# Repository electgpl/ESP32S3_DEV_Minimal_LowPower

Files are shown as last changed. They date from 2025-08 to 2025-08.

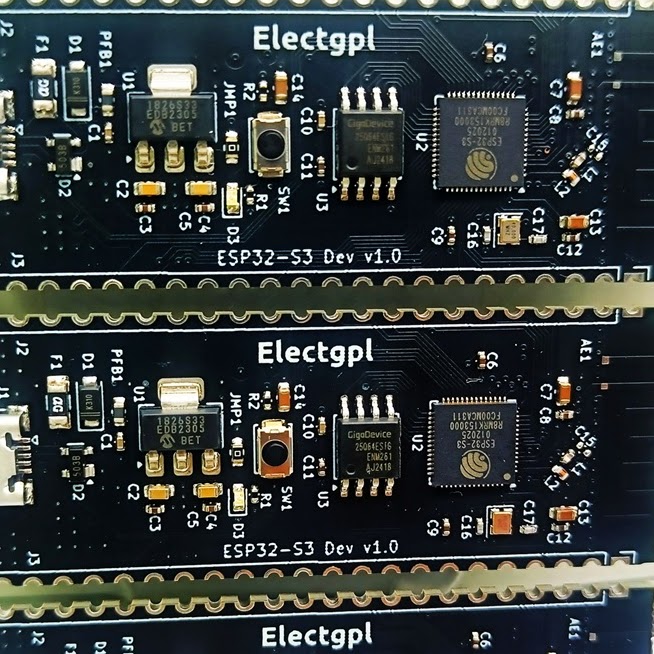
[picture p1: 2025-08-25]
Resources/wKgZO2gYVwOAP5xqADixpduBXg466aaa.jpg

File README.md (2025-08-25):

# ESP32S3_DEV_Minimal_LowPower

This project implements a **minimal low-power development board** based on the **ESP32-S3**.  
The design focuses on reducing component count, board complexity, and idle power consumption, while still exposing the full capabilities of the ESP32-S3 for advanced development.  

Unlike traditional development boards, this design does **not include a USB-to-UART bridge**. Instead, it leverages the **native USB interface** of the ESP32-S3 for programming and communication, resulting in a simpler and more efficient design.  

---

## 🔑 Features

- **ESP32-S3 MCU** with external **QSPI Flash memory**.  
- **Native USB 2.0 interface** used for flashing and serial communication.  
- **MCP1826S LDO regulator**:  
  - Low quiescent current (IQ) for low-power operation.  
  - Stable supply for ESP32-S3 core.  
- **4-layer PCB**:  
  - Designed and manufactured at **NextPCB (PCBA service)**.  
  - Optimized for **low EMI/EMC compliance**.  
- **Castellated edges** for easy integration into other projects.  
- **Full pinout exposure**:  
  - All ESP32-S3 GPIOs available, including those not accessible on standard WROOM modules.  
  - Enables advanced use cases and maximum flexibility.  
- **On-board PCB antenna (MIFA type)**:  
  - Designed with **uSimmics EM simulation**.  
  - Verified radiation characteristics, dispersion parameters, and stack-up effects.  

---

## 📂 Repository structure

- **/schematic/** → Circuit schematic files.  
- **/pcb/** → PCB layout and Gerber files.  
- **/doc/** → Antenna simulation results and design notes.  
- **/firmware/** → Demo applications and example projects.  
- **/img/** → PCB renders and prototype photos.  

---

## 🧪 Demo Application

Included with this project is a **human presence detection demo** based on Wi-Fi spectral footprint analysis:  

- Scans available Wi-Fi networks, collecting **SSID** and **RSSI** values.  
- Applies a **probability-based algorithm** using **normal distribution** to estimate environmental changes.  
- Detects human presence based on variations in the Wi-Fi spectrum.  
- Displays results on a **color IPS display**.  

This demonstrates the potential of the ESP32-S3 in **low-cost sensing and AIoT applications** without requiring dedicated motion sensors.  

---

## 🔧 Typical applications

- Low-power IoT node development.  
- Integration into custom PCBs via castellated module design.  
- Edge-AI and machine learning applications.  
- Antenna research and RF prototyping.  

---

## 📑 References

- [ESP32-S3 Technical Reference Manual (Espressif)](https://www.espressif.com/en/support/download/technical-documents)  
- [MCP1826S LDO Datasheet (Microchip)](https://ww1.microchip.com/downloads/en/DeviceDoc/22057B.pdf)  
- [uSimmics EM Simulation Software](https://www.usimmics.com/)  

---

## 📸 Project preview

*(Insert here PCB renders, antenna simulation plots, and prototype photos)*  

---

## ⚖️ License

This project is released under the **MIT License**.  
You are free to use, modify, and distribute it, provided that proper credit is given.  

---

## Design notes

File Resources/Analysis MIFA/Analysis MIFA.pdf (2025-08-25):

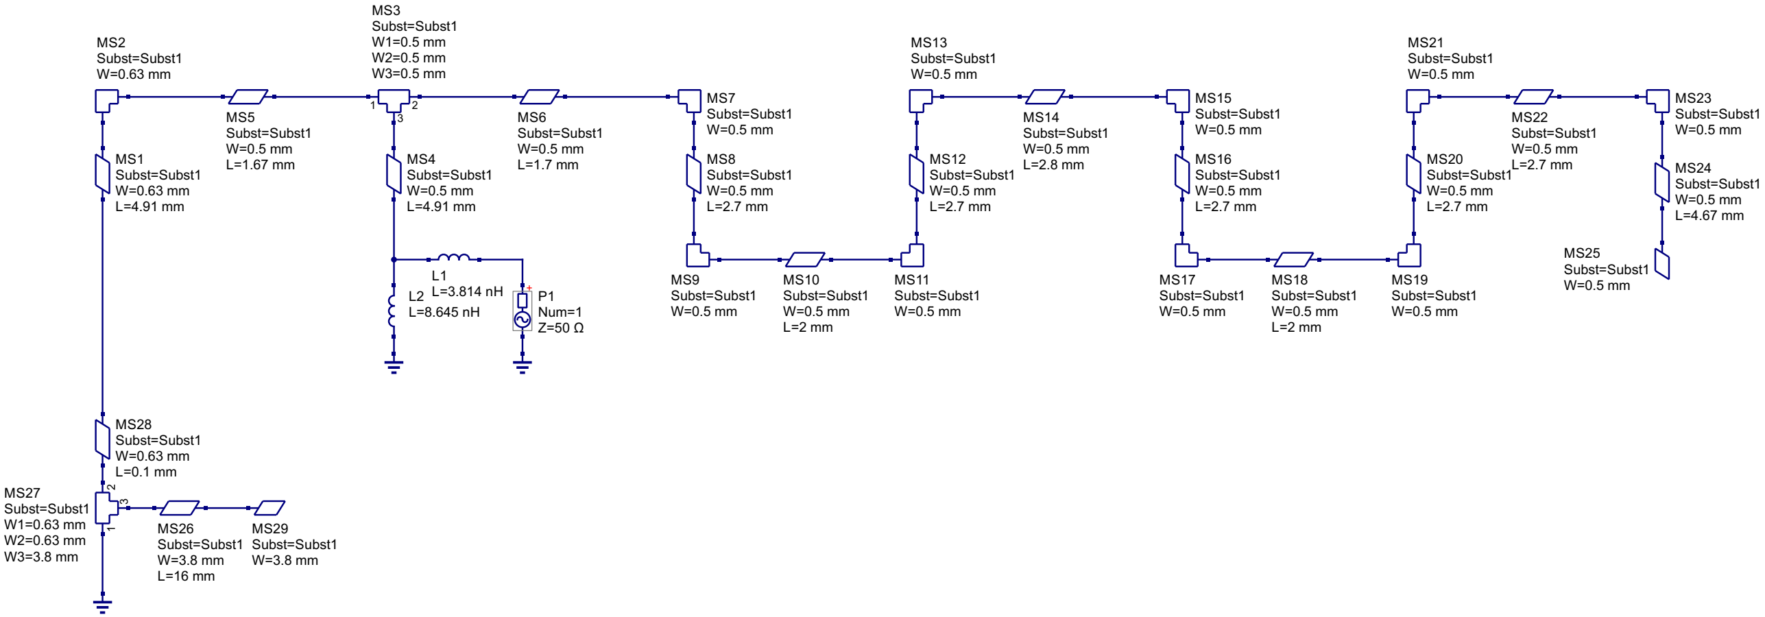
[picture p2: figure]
MS1 Subst=Subst1 W=0.63 mm L=4.91 mm; MS2 Subst=Subst1 W=0.63 mm; MS5 Subst=Subst1 W=0.5 mm L=1.67 mm; MS6 Subst=Subst1 W=0.5 mm L=1.7 mm; MS3 Subst=Subst1 W1=0.5 mm W2=0.5 mm W3=0.5 mm; MS4 Subst=Subst1 W=0.5 mm L=4.91 mm; MS7 Subst=Subst1 W=0.5 mm; MS8 Subst=Subst1 W=0.5 mm L=2.7 mm; MS9 Subst=Subst1 W=0.5 mm; MS10 Subst=Subst1 W=0.5 mm L=2 mm; MS11 Subst=Subst1 W=0.5 mm; MS12 Subst=Subst1 W=0.5 mm L=2.7 mm; MS14 Subst=Subst1 W=0.5 mm L=2.8 mm; MS15 Subst=Subst1 W=0.5 mm; MS16 Subst=Subst1 W=0.5 mm L=2.7 mm; MS17 Subst=Subst1 W=0.5 mm; MS18 Subst=Subst1 W=0.5 mm L=2 mm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

Subst1
er=4.5
h=1.6 mm
t=35 µm
tand=2e-4
rho=1.72e-8
backside=Metal

### s-parameter simulation

SP1
Type=lin Start=2.3 GHz Stop=2.5 GHz Points=1000

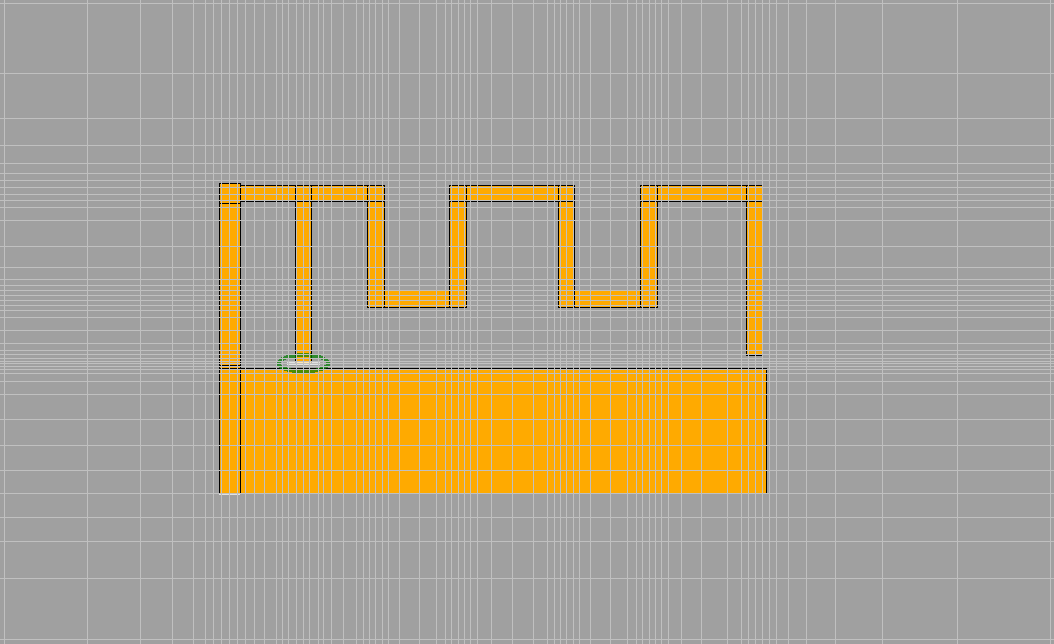
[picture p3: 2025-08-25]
Resources/Analysis MIFA/Captura de pantalla 2025-07-07 103250.png

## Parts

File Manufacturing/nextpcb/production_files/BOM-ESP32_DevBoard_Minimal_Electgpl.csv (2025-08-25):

MPN | Qty | Designator | value | manufacturer | Category | SKU | Customer Supply | Customer Remark
 | 1 | AE1 | Antenna_Shield
 | 6 | C7,C14,C5,C2,C13,PFB1 | 10u
 | 14 | C11,C12,C9,C4,C17,C6,C8,L1,C3,C1,C10,C15,L2,C16 | 100n
 | 1 | D1 | DS310W
 | 1 | D2 | SP0503BAHTG
 | 1 | D3 | LED
 | 1 | F1 | nSMD150
 | 1 | J1 | U254-051T-4BH83-F1S
 | 2 | J3,J2 | Conn_01x22_Pin
 | 1 | JMP1 | 0R
 | 2 | R1,R2 | 10k
 | 1 | SW1 | SW_Push
 | 1 | U1 | MCP1826S-3302E/DB
 | 1 | U2 | ESP32-S3
 | 1 | U3 | W25Q64JVSSIQ
 | 1 | Y1 | R940000096

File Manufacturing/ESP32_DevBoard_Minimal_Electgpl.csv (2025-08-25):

Designator* | Quantity* | Manufacturer Part Number* | Manufacturer | Package/Footprint | Description | Procurement Type | Customer Note
AE1 | 1 |  |  | ESP_Antenna:ESPRESSIF_ESP32_MIFA_2.4GHz_Right |  | DNP
C1,C10 | 2 | CL05X105KP5NNNC |  | Capacitor_SMD:C_0402_1005Metric |  |  | CA0157860
C2,C5 | 2 | GRM188R60J476ME15D |  | Capacitor_SMD:C_0603_1608Metric |  |  | CA0135493
C3,C4,C6,C8,C9,C11,C12 | 7 | CC0402KRX7R9BB104 |  | Capacitor_SMD:C_0402_1005Metric |  |  | RE0187778
C7,C13,C14 | 3 | GCM188D70J106ME36D |  | Capacitor_SMD:C_0603_1608Metric |  |  | CA0384128
C15 | 1 |  |  | Capacitor_SMD:C_0402_1005Metric |  | DNP
C16,C17 | 2 | GRM1555C1H100GA01D |  | Capacitor_SMD:C_0402_1005Metric |  |  | CA0137027
D1 | 1 | DS310W |  | Diode_SMD:D_SOD-123 |  |  | DS0182252
D2 | 1 | SP0503BAHTG |  | Package_TO_SOT_SMD:SOT-143 |  |  | CP0003989
D3 | 1 | TJ-S1608B06HQYJY-A3 |  | LED_SMD:LED_0603_1608Metric |  |  | PH0093820
F1 | 1 | nSMD075-16V |  | Fuse:Fuse_1206_3216Metric_Pad1.42x1.75mm_HandSolder |  |  | CP0107097
J1 | 1 | U254-051T-4BH83-F1S |  | Connector_USB:USB_Micro-B_XKB_U254-051T-4BH83-F1S |  |  | CO0893195
J2,J3 | 2 |  |  | Connector_PinHeader_2.54mm:PinHeader_1x22_P2.54mm_Vertical |  | DNP
JMP1 | 1 | AC0603JR-070RL |  | Resistor_SMD:R_0603_1608Metric |  |  | RE0030890
L1 | 1 | SCC1005C4N3SSP |  | Capacitor_SMD:C_0402_1005Metric |  |  | IN0076375
L2 | 1 | SCW1005C8N2JST |  | Capacitor_SMD:C_0402_1005Metric |  |  | IN0074484
PFB1 | 1 | BLM18SG331TN1D |  | Capacitor_SMD:C_0603_1608Metric |  |  | WF0011783
R1,R2 | 2 | RC0402JR-0710KL |  | Resistor_SMD:R_0402_1005Metric |  |  | RE0023874
SW1 | 1 | SKRKAEE020 |  | Button_Switch_SMD:SW_Push_SPST_NO_Alps_SKRK |  |  | SW0049182
U1 | 1 | MCP1826S-3302E/DB |  | Package_TO_SOT_SMD:SOT-223 |  |  | IC0133633
U2 | 1 | ESP32-S3R8 |  | Package_DFN_QFN:QFN-56-1EP_7x7mm_P0.4mm_EP5.6x5.6mm |  |  | RF15788811
U3 | 1 | GD25Q64ESIG |  | Package_SO:SOP-8_5.28x5.23mm_P1.27mm |  |  | IC0447018
Y1 | 1 | TAXM40M4ZHBCDT2T |  | Crystal:Crystal_SMD_2016-4Pin_2.0x1.6mm |  |  | C7206306

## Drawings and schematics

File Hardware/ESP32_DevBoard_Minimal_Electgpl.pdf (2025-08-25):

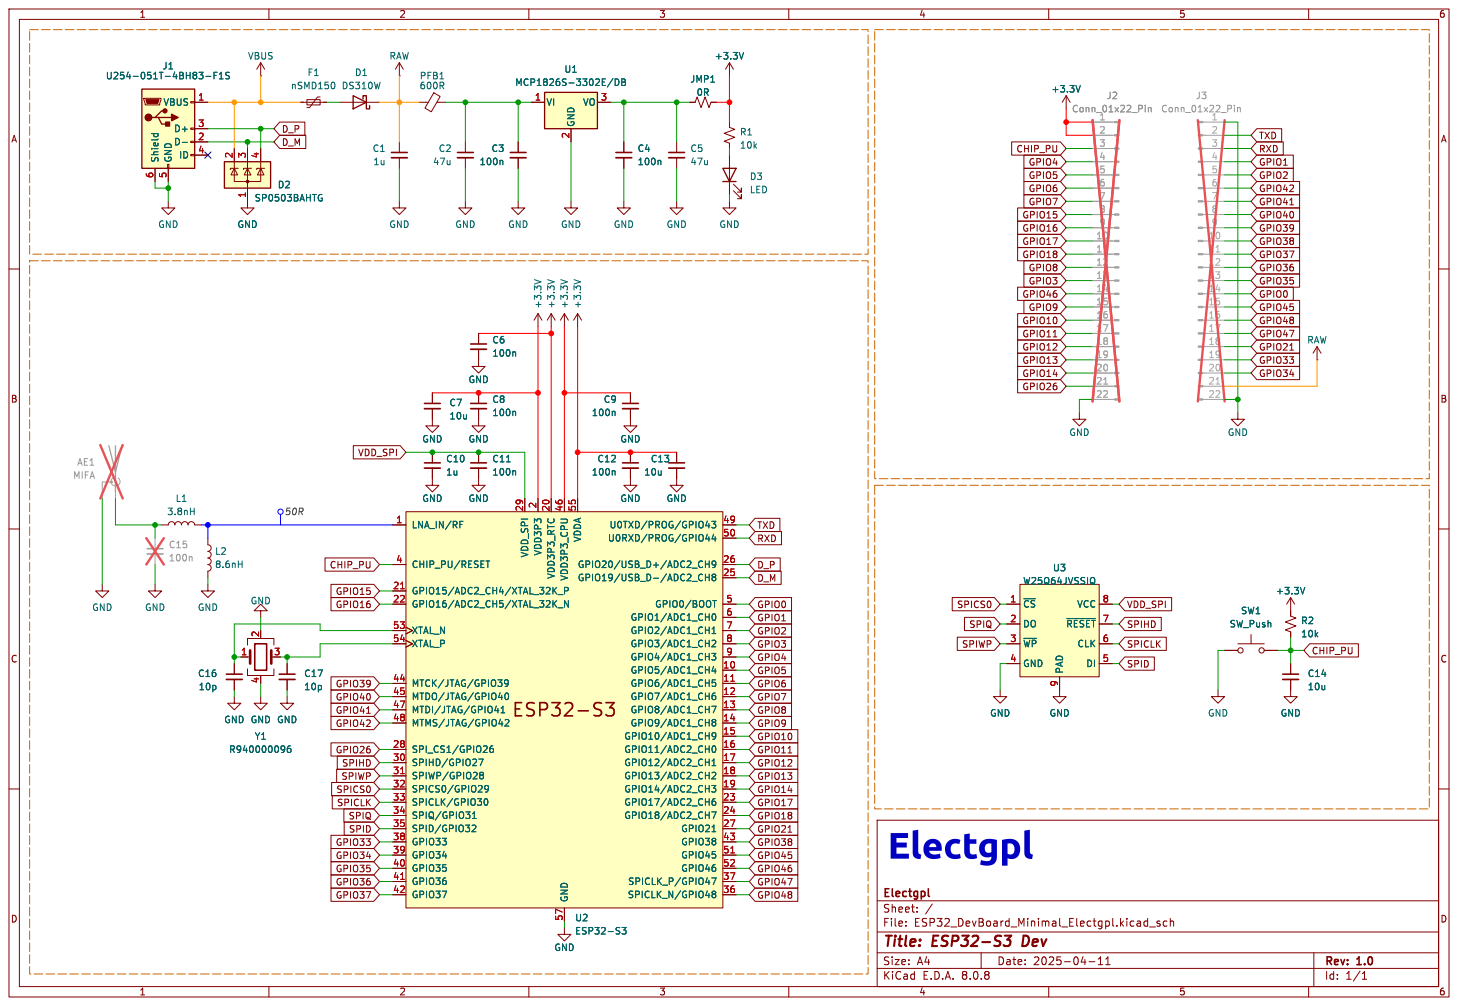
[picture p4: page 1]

2 VDD3P3_RTC 20 GPIO15/ADC2_CH4/XTAL_32K_P 21 GPIO16/ADC2_CH5/XTAL_32K_N 22 GPIO17/ADC2_CH6 23 GPIO18/ADC2_CH7 24 GPIO19/USB_D-/ADC2_CH8 25 GPIO20/USB_D+/ADC2_CH9 26 GPIO21 27 SPI_CS1/GPIO26 28 VDD_SPI 29 SPIHD/GPIO27 30 SPIWP/GPIO28 31 SPICS0/GPIO29 32 SPICLK/GPIO30 33 SPIQ/GPIO31 34 SPID/GPIO32 35 GPIO33 38 GPIO34 39 CHIP_PU/RESET 4 GPIO35 40 GPIO36 41 GPIO37 42 GPIO38 43 MTCK/JTAG/GPIO39 44 MTDO/JTAG/GPIO40 45 VDD3P3_CPU 46 MTDI/JTAG/GPIO41 47 MTMS/JTAG/GPIO42 48 U0TXD/PROG/GPIO43 49 GPIO0/BOOT 5 U0RXD/PROG/GPIO44 50 GPIO45 51 GPIO46 52 XTAL_N 53 XTAL_P 54 VDDA 55 GND 57 GPIO1/ADC1_CH0 6 GPIO2/ADC1_CH1 7 GPIO3/ADC1_CH2 8 GPIO4/ADC1_CH3 9 U2ESP32-S3

2 VDD3P3_RTC 20 GPIO15/ADC2_CH4/XTAL_32K_P 21 GPIO16/ADC2_CH5/XTAL_32K_N 22 GPIO17/ADC2_CH6 23 GPIO18/ADC2_CH7 24 GPIO19/USB_D-/ADC2_CH8 25 GPIO20/USB_D+/ADC2_CH9 26 GPIO21 27 SPI_CS1/GPIO26 28 VDD_SPI 29 SPIHD/GPIO27 30 SPIWP/GPIO28 31 SPICS0/GPIO29 32 SPICLK/GPIO30 33 SPIQ/GPIO31 34 SPID/GPIO32 35 GPIO33 38 GPIO34 39 CHIP_PU/RESET 4 GPIO35 40 GPIO36 41 GPIO37 42 GPIO38 43 MTCK/JTAG/GPIO39 44 MTDO/JTAG/GPIO40 45 VDD3P3_CPU 46 MTDI/JTAG/GPIO41 47 MTMS/JTAG/GPIO42 48 U0TXD/PROG/GPIO43 49 GPIO0/BOOT 5 U0RXD/PROG/GPIO44 50 GPIO45 51 GPIO46 52 XTAL_N 53 XTAL_P 54 VDDA 55 GND 57 GPIO1/ADC1_CH0 6 GPIO2/ADC1_CH1 7 GPIO3/ADC1_CH2 8 GPIO4/ADC1_CH3 9 GND

File: ESP32_DevBoard_Minimal_Electgpl.kicad_sch Sheet: / Electgpl GND

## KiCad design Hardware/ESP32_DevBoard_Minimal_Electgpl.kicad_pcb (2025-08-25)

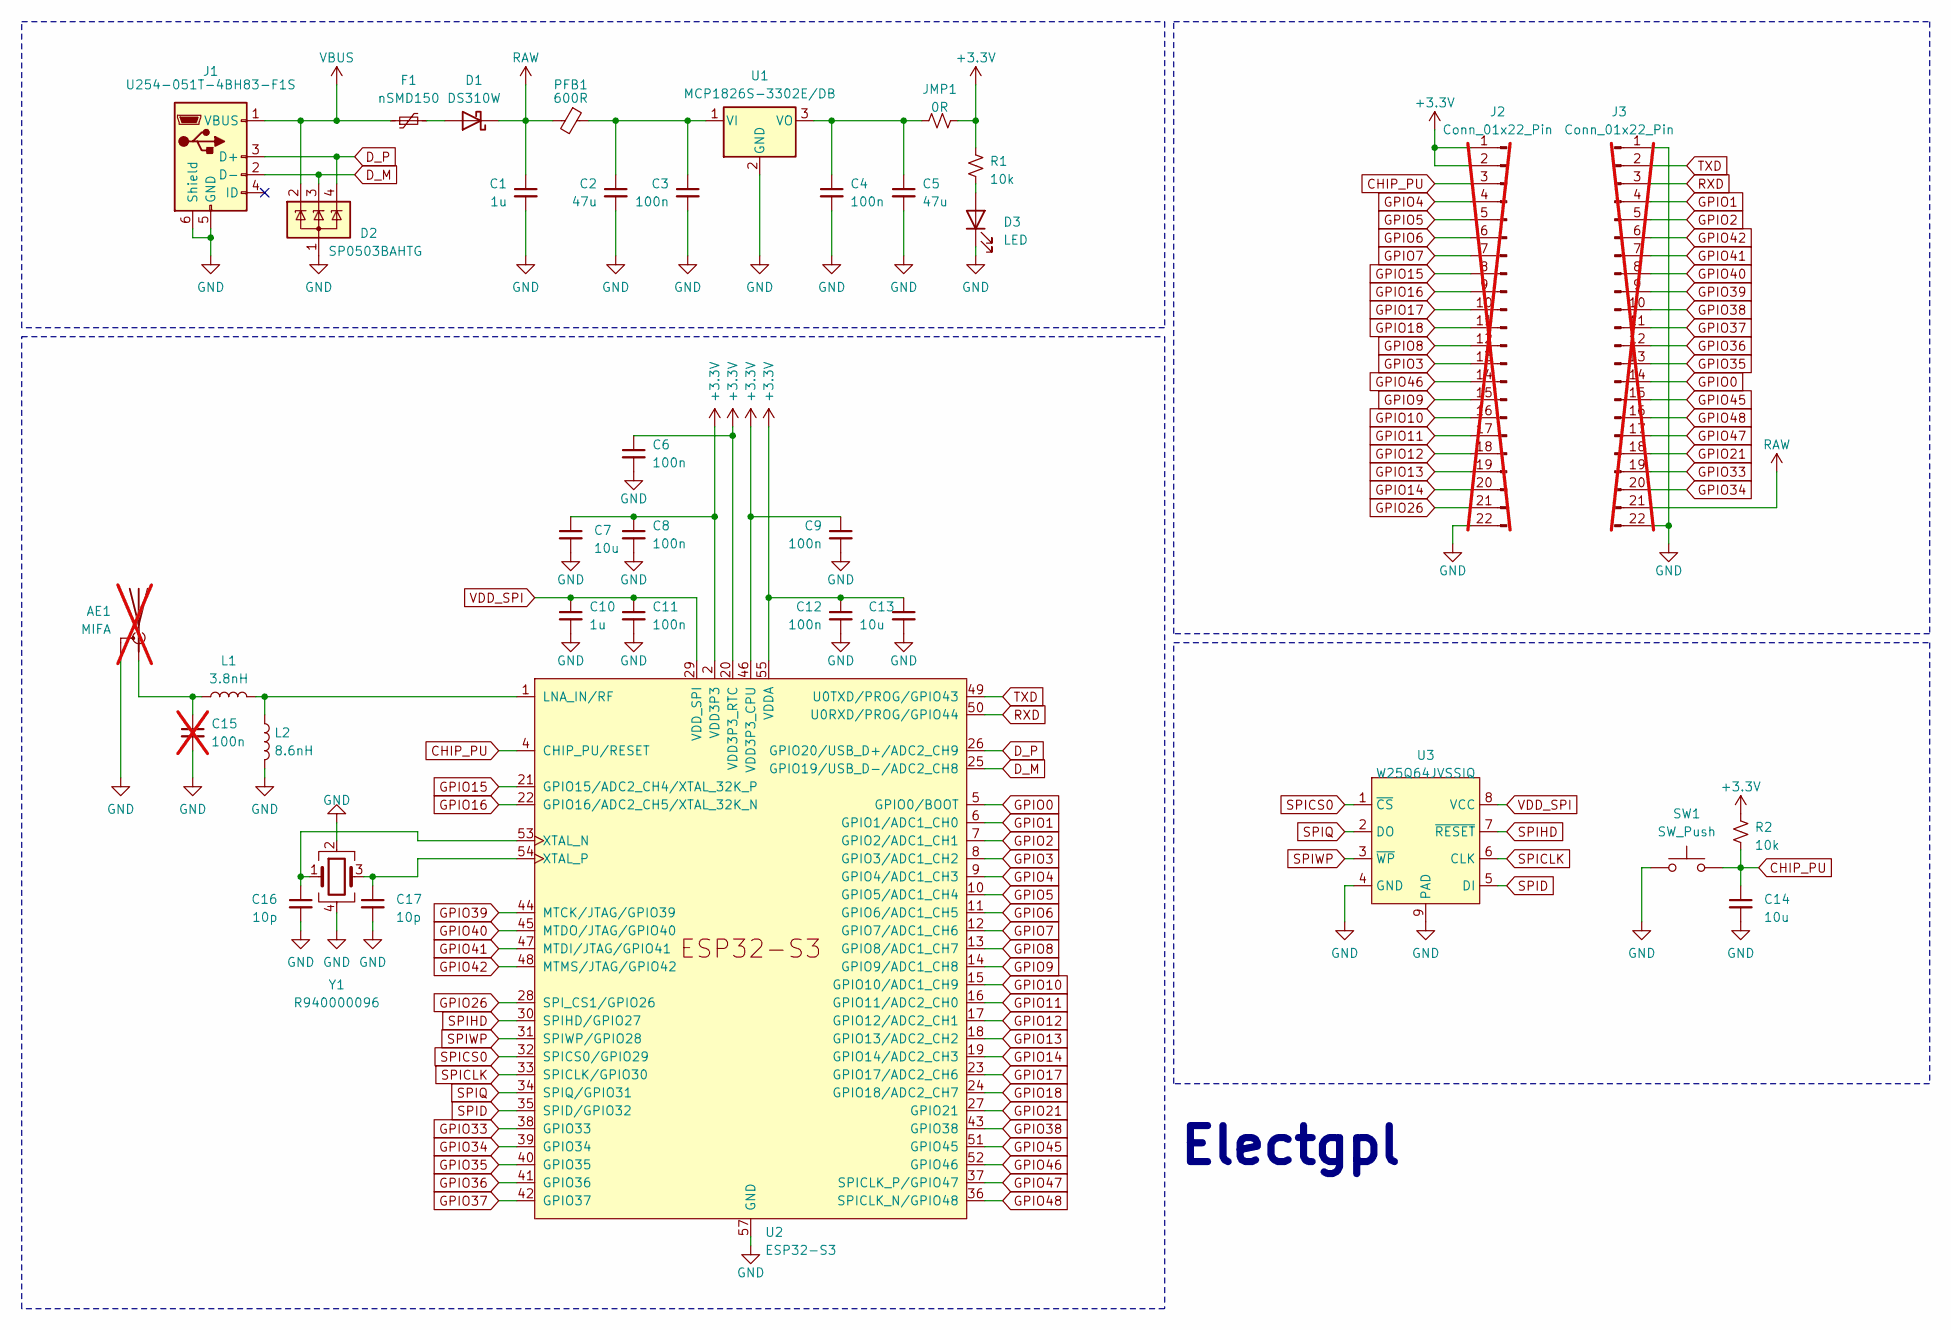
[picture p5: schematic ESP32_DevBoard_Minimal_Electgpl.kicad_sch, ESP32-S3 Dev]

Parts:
AE1: MIFA; ESPRESSIF_ESP32_MIFA_2.4GHz_Right; not fitted
C1, C10: 1u; C_0402_1005Metric; MFR P/N CL05X105KP5NNNC; LCSC CA0157860
C2, C5: 47u; C_0603_1608Metric; MFR P/N GRM188R60J476ME15D; LCSC CA0135493
C3, C4, C6, C8, C9, C11, C12: 100n; C_0402_1005Metric; MFR P/N CC0402KRX7R9BB104; LCSC RE0187778
C7, C13, C14: 10u; C_0603_1608Metric; MFR P/N GCM188D70J106ME36D; LCSC CA0384128
C15: 100n; C_0402_1005Metric; not fitted
C16, C17: 10p; C_0402_1005Metric; MFR P/N GRM1555C1H100GA01D; LCSC CA0137027
D1: DS310W; D_SOD-123; MFR P/N DS310W; LCSC DS0182252
D2: SP0503BAHTG; SOT-143; MFR P/N SP0503BAHTG; LCSC CP0003989
D3: LED; LED_0603_1608Metric; MFR P/N TJ-S1608B06HQYJY-A3; LCSC PH0093820
F1: nSMD150; Fuse_1206_3216Metric_Pad1.42x1.75mm_HandSolder; MFR P/N nSMD075-16V; LCSC CP0107097
J1: U254-051T-4BH83-F1S; USB_Micro-B_XKB_U254-051T-4BH83-F1S; MFR P/N U254-051T-4BH83-F1S; LCSC CO0893195
J2, J3: Conn_01x22_Pin; PinHeader_1x22_P2.54mm_Vertical; not fitted
JMP1: 0R; R_0603_1608Metric; MFR P/N AC0603JR-070RL; LCSC RE0030890
L1: 3.8nH; C_0402_1005Metric; MFR P/N SCC1005C4N3SSP; LCSC IN0076375
L2: 8.6nH; C_0402_1005Metric; MFR P/N SCW1005C8N2JST; LCSC IN0074484
PFB1: 600R; C_0603_1608Metric; MFR P/N BLM18SG331TN1D; LCSC WF0011783
R1, R2: 10k; R_0402_1005Metric; MFR P/N RC0402JR-0710KL; LCSC RE0023874
SW1: SW_Push; SW_Push_SPST_NO_Alps_SKRK; MFR P/N SKRKAEE020; LCSC SW0049182
U1: MCP1826S-3302E/DB; SOT-223; MFR P/N MCP1826S-3302E/DB; LCSC IC0133633
U2: ESP32-S3; QFN-56-1EP_7x7mm_P0.4mm_EP5.6x5.6mm; MFR P/N ESP32-S3R8; LCSC RF15788811
U3: W25Q64JVSSIQ; SOP-8_5.28x5.23mm_P1.27mm; MFR P/N GD25Q64ESIG; LCSC IC0447018
Y1: R940000096; Crystal_SMD_2016-4Pin_2.0x1.6mm; MFR P/N TAXM40M4ZHBCDT2T; LCSC C7206306

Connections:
+3.3V: C6.1, C7.1, C8.1, C9.1, C12.1, C13.1, J2.1, J2.2, JMP1.2, R1.1, R2.1, U2.2 (VDD3P3), U2.3 (VDD3P3), U2.20 (VDD3P3_RTC), U2.46 (VDD3P3_CPU), U2.55 (VDDA), U2.56 (VDDA)
CHIP_PU: C14.1, J2.3, R2.2, SW1.2, U2.4 (CHIP_PU/RESET)
D_M: D2.3 (K), J1.2 (D-), U2.25 (GPIO19/USB_D-/ADC2_CH8)
D_P: D2.4 (K), J1.3 (D+), U2.26 (GPIO20/USB_D+/ADC2_CH9)
GND: AE1.2 (Shield), C1.2, C2.2, C3.2, C4.2, C5.2, C6.2, C7.2, C8.2, C9.2, C10.2, C11.2, C12.2, C13.2, C14.2, C15.2, C16.2, C17.2, D2.1 (A), D3.1 (K), J1.5 (GND), J1.6 (Shield), J2.22, J3.1, J3.22, L2.2, SW1.1, U1.2 (GND), U2.57 (GND), U3.4 (GND), U3.9 (PAD), Y1.2, Y1.4
GPIO0: J3.14, U2.5 (GPIO0/BOOT)
GPIO1: J3.4, U2.6 (GPIO1/ADC1_CH0)
GPIO2: J3.5, U2.7 (GPIO2/ADC1_CH1)
GPIO3: J2.13, U2.8 (GPIO3/ADC1_CH2)
GPIO4: J2.4, U2.9 (GPIO4/ADC1_CH3)
GPIO5: J2.5, U2.10 (GPIO5/ADC1_CH4)
GPIO6: J2.6, U2.11 (GPIO6/ADC1_CH5)
GPIO7: J2.7, U2.12 (GPIO7/ADC1_CH6)
GPIO8: J2.12, U2.13 (GPIO8/ADC1_CH7)
GPIO9: J2.15, U2.14 (GPIO9/ADC1_CH8)
GPIO10: J2.16, U2.15 (GPIO10/ADC1_CH9)
GPIO11: J2.17, U2.16 (GPIO11/ADC2_CH0)
GPIO12: J2.18, U2.17 (GPIO12/ADC2_CH1)
GPIO13: J2.19, U2.18 (GPIO13/ADC2_CH2)
GPIO14: J2.20, U2.19 (GPIO14/ADC2_CH3)
GPIO15: J2.8, U2.21 (GPIO15/ADC2_CH4/XTAL_32K_P)
GPIO16: J2.9, U2.22 (GPIO16/ADC2_CH5/XTAL_32K_N)
GPIO17: J2.10, U2.23 (GPIO17/ADC2_CH6)
GPIO18: J2.11, U2.24 (GPIO18/ADC2_CH7)
GPIO21: J3.18, U2.27 (GPIO21)
GPIO26: J2.21, U2.28 (SPI_CS1/GPIO26)
GPIO33: J3.19, U2.38 (GPIO33)
GPIO34: J3.20, U2.39 (GPIO34)
GPIO35: J3.13, U2.40 (GPIO35)
GPIO36: J3.12, U2.41 (GPIO36)
GPIO37: J3.11, U2.42 (GPIO37)
GPIO38: J3.10, U2.43 (GPIO38)
GPIO39: J3.9, U2.44 (MTCK/JTAG/GPIO39)
GPIO40: J3.8, U2.45 (MTDO/JTAG/GPIO40)
GPIO41: J3.7, U2.47 (MTDI/JTAG/GPIO41)
GPIO42: J3.6, U2.48 (MTMS/JTAG/GPIO42)
GPIO45: J3.15, U2.51 (GPIO45)
GPIO46: J2.14, U2.52 (GPIO46)
GPIO47: J3.17, U2.37 (SPICLK_P/GPIO47)
GPIO48: J3.16, U2.36 (SPICLK_N/GPIO48)
unnamed: AE1.1 (A), C15.1, L1.1
unnamed: D1.2 (A), F1.2
unnamed: D3.2 (A), R1.2
unnamed: C2.1, C3.1, PFB1.1, U1.1 (VI)
unnamed: C4.1, C5.1, JMP1.1, U1.3 (VO)
unnamed: L1.2, L2.1, U2.1 (LNA_IN/RF)
unnamed: C16.1, U2.53 (XTAL_N), Y1.1
unnamed: C17.1, U2.54 (XTAL_P), Y1.3
RAW: C1.1, D1.1 (K), J3.21, PFB1.2
RXD: J3.3, U2.50 (U0RXD/PROG/GPIO44)
SPICLK: U2.33 (SPICLK/GPIO30), U3.6 (CLK)
SPICS0: U2.32 (SPICS0/GPIO29), U3.1 (~CS)
SPID: U2.35 (SPID/GPIO32), U3.5 (DI)
SPIHD: U2.30 (SPIHD/GPIO27), U3.7 (~RESET)
SPIQ: U2.34 (SPIQ/GPIO31), U3.2 (DO)
SPIWP: U2.31 (SPIWP/GPIO28), U3.3 (~WP)
TXD: J3.2, U2.49 (U0TXD/PROG/GPIO43)
VBUS: D2.2 (K), F1.1, J1.1 (VBUS)
VDD_SPI: C10.1, C11.1, U2.29 (VDD_SPI), U3.8 (VCC)

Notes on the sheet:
Electgpl

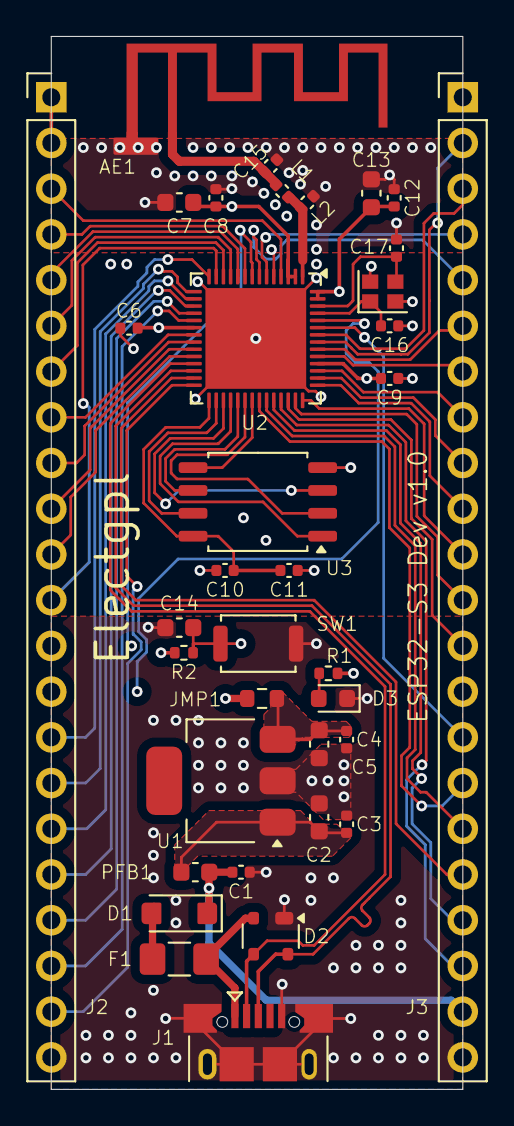
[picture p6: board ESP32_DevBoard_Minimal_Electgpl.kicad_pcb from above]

Board: 4 copper layers, 22.9 x 58.5 mm, 36 parts (0 on the bottom side), 59 nets.

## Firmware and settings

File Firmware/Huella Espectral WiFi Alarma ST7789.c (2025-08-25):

#include <WiFi.h>
#include <Adafruit_GFX.h>
#include <Adafruit_ST7789.h>
#include <SPI.h>

#define TFT_CS    10
#define TFT_DC    9
#define TFT_RST   8
#define TFT_MOSI  11  //SDA en Pantalla
#define TFT_SCLK  12  //SCK en Pantalla
#define TFT_BLK   7

Adafruit_ST7789 tft = Adafruit_ST7789(TFT_CS, TFT_DC, TFT_RST);

struct APData {
  String bssid;
  float rssi_sum = 0;
  float rssi_sum_sq = 0;
  int count = 0;
  float mean = 0;
  float stddev = 1.0;
  float lastDiffNorm = 0;
};

#include <vector>
std::vector<APData> calibrationData;

const unsigned long CALIBRATION_TIME_MS = 30000;
const unsigned long SCAN_INTERVAL_MS = 2000;
const float THRESHOLD = 25.0;

unsigned long calibrationStart = 0;
bool calibrated = false;

void setup() {
  Serial.begin(115200);
  while (!Serial) delay(10);  //Demora porque el S3 a veces tarda un poco mas en mandar los datos por UART tras el boot

  pinMode(TFT_BLK, OUTPUT);
  digitalWrite(TFT_BLK, HIGH); // Enciende la retroiluminación

  tft.init(240, 240, SPI_MODE3);
  tft.setRotation(2);
  tft.fillScreen(ST77XX_BLACK);
  tft.setTextColor(ST77XX_WHITE);
  tft.setTextSize(3);
  tft.setCursor(10, 10);
  tft.print("Electgpl");
  tft.setTextSize(2);
  tft.setCursor(10, 50);
  tft.print("Huella Espectral");
  tft.setCursor(10, 70);
  tft.print("Espera Colocacion");

  WiFi.mode(WIFI_STA);
  WiFi.disconnect();

  Serial.println("Coloque el ESP32 sin movimiento...");
  calibrationStart = millis();
}

void loop() {
  if (!calibrated) {
    if (millis() - calibrationStart < CALIBRATION_TIME_MS) {
      scanAndAccumulate();
      delay(SCAN_INTERVAL_MS);
    } else {
      computeCalibrationStats();
      calibrated = true;
      Serial.println("Calibracion terminada.");
      tft.fillScreen(ST77XX_BLACK);
      tft.setCursor(10, 10);
      tft.println("Ararma Activa");
      delay(1000);
    }
  } else {
    bool alarm = detectAndDraw();
    if (alarm) {
      Serial.println(">>> ALARMA <<<");
      drawAlarm();
      delay(1000);
    }
    delay(SCAN_INTERVAL_MS);
  }
}

void scanAndAccumulate() {
  int n = WiFi.scanNetworks(false, true, false, 300);
  if (n == 0) return;

  for (int i = 0; i < n; i++) {
    String bssid = WiFi.BSSIDstr(i);
    int rssi = WiFi.RSSI(i);
    int idx = findAPIndex(bssid);
    if (idx < 0) {
      APData newAP;
      newAP.bssid = bssid;
      newAP.rssi_sum = rssi;
      newAP.rssi_sum_sq = rssi * rssi;
      newAP.count = 1;
      calibrationData.push_back(newAP);
    } else {
      calibrationData[idx].rssi_sum += rssi;
      calibrationData[idx].rssi_sum_sq += rssi * rssi;
      calibrationData[idx].count++;
    }
  }
  WiFi.scanDelete();
}

int findAPIndex(const String &bssid) {
  for (int i = 0; i < (int)calibrationData.size(); i++) {
    if (calibrationData[i].bssid == bssid) return i;
  }
  return -1;
}

void computeCalibrationStats() {
  for (auto &ap : calibrationData) {
    if (ap.count > 0) {
      ap.mean = ap.rssi_sum / ap.count;
      float var = (ap.rssi_sum_sq / ap.count) - (ap.mean * ap.mean);
      ap.stddev = sqrt(var);
      if (ap.stddev < 1.0) ap.stddev = 1.0;
    }
    Serial.printf("AP %s: mean=%.1f, std=%.1f, count=%d\n",
                  ap.bssid.c_str(), ap.mean, ap.stddev, ap.count);
  }
}

bool detectAndDraw() {
  int n = WiFi.scanNetworks(false, true, false, 100);
  if (n == 0) return false;

  float totalDiff = 0;
  int maxBars = min(16, (int)calibrationData.size());
  int barWidth = 240 / maxBars;

  tft.fillScreen(ST77XX_BLACK);
  // Dibujar línea de umbral
  for (int x = 0; x < 240; x += 4) {
    tft.drawPixel(x, 30, ST77XX_CYAN);
  }

  for (int i = 0; i < maxBars; i++) {
    APData &ap = calibrationData[i];
    int idx = -1;
    for (int j = 0; j < n; j++) {
      if (WiFi.BSSIDstr(j) == ap.bssid) {
        idx = j;
        break;
      }
    }

    float diffNorm = 0;
    if (idx >= 0) {
      int rssi_now = WiFi.RSSI(idx);
      diffNorm = fabs(rssi_now - ap.mean) / ap.stddev;
    } else {
      diffNorm = 3.0;
    }
    ap.lastDiffNorm = diffNorm;
    totalDiff += diffNorm;

    // Dibujar barra
    int barHeight = min(200, (int)(diffNorm * 40)); // escala ajustable
    int x = i * barWidth;
    int y = 240 - barHeight;

    uint16_t color = ST77XX_GREEN;
    if (diffNorm > 2.0) color = ST77XX_RED;
    else if (diffNorm > 1.0) color = ST77XX_YELLOW;

    tft.fillRect(x + 2, y, barWidth - 4, barHeight, color);

    // UART
    Serial.printf("%s, diff=%.2f\n", ap.bssid.c_str(), diffNorm);
  }

  tft.setCursor(10, 10);
  tft.setTextColor(ST77XX_WHITE);
  tft.setTextSize(2);
  tft.printf("Diff: %.1f\n", totalDiff);

  WiFi.scanDelete();

  return (totalDiff > THRESHOLD);
}

void drawAlarm() {
  tft.fillScreen(ST77XX_RED);
  tft.setCursor(60, 100);
  tft.setTextColor(ST77XX_WHITE);
  tft.setTextSize(3);
  tft.println("ALARMA");
}

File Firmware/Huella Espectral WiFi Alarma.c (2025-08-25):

#include <WiFi.h>

struct APData {
  String bssid;
  float rssi_sum = 0;
  float rssi_sum_sq = 0;
  int count = 0;
  float mean = 0;
  float stddev = 0;
};

#include <vector>
std::vector<APData> calibrationData;

const unsigned long CALIBRATION_TIME_MS = 30000;
const unsigned long SCAN_INTERVAL_MS = 2000;
const float THRESHOLD = 25.0;  // Ajustar según sensibilidad deseada

unsigned long calibrationStart = 0;
bool calibrated = false;

void setup() {
  Serial.begin(115200);
  while (!Serial) {
     delay(10);
  }
  Serial.println("UART Init");
  WiFi.mode(WIFI_STA);
  WiFi.disconnect(); // Para evitar conexión automática

  Serial.println("Colocar el ESP32S3 sin movimiento para calibracion (30 segundos)...");
  calibrationStart = millis();
}

void loop() {
  if (!calibrated) {
    // Durante calibracion
    if (millis() - calibrationStart < CALIBRATION_TIME_MS) {
      scanAndAccumulate();
      delay(SCAN_INTERVAL_MS);
    } else {
      computeCalibrationStats();
      calibrated = true;
      Serial.println("Calibracion terminada. Modo activo.");
    }
  } else {
    // Modo activo
    bool alarm = detectMovement();
    if (alarm) {
      Serial.println("<<<<<<<<<<  ALARMA  >>>>>>>>>>");
    }
    delay(SCAN_INTERVAL_MS);
  }
}

void scanAndAccumulate() {
  int n = WiFi.scanNetworks(false, true, false, 300);
  if (n == 0) {
    Serial.println("No se detectaron APs durante calibracion");
    return;
  }

  for (int i = 0; i < n; i++) {
    String bssid = WiFi.BSSIDstr(i);
    int rssi = WiFi.RSSI(i);

    int idx = findAPIndex(bssid);
    if (idx < 0) {
      // Nuevo AP
      APData newAP;
      newAP.bssid = bssid;
      newAP.rssi_sum = rssi;
      newAP.rssi_sum_sq = rssi * rssi;
      newAP.count = 1;
      calibrationData.push_back(newAP);
    } else {
      // AP existente, acumular
      calibrationData[idx].rssi_sum += rssi;
      calibrationData[idx].rssi_sum_sq += rssi * rssi;
      calibrationData[idx].count++;
    }
  }
  WiFi.scanDelete();
}

int findAPIndex(const String &bssid) {
  for (int i = 0; i < (int)calibrationData.size(); i++) {
    if (calibrationData[i].bssid == bssid) {
      return i;
    }
  }
  return -1;
}

void computeCalibrationStats() {
  for (auto &ap : calibrationData) {
    if (ap.count > 0) {
      ap.mean = ap.rssi_sum / ap.count;
      float variance = (ap.rssi_sum_sq / ap.count) - (ap.mean * ap.mean);
      ap.stddev = (variance > 0) ? sqrt(variance) : 1.0; // mínimo stddev para evitar división por cero
    } else {
      ap.mean = 0;
      ap.stddev = 1.0;
    }
    // Debug
    Serial.printf("AP %s: media=%.2f dBm, std=%.2f dBm, muestras=%d\n",
                  ap.bssid.c_str(), ap.mean, ap.stddev, ap.count);
  }
}

bool detectMovement() {
  int n = WiFi.scanNetworks(false, true, false, 300); // passive scan 300ms
  if (n == 0) {
    Serial.println("No se detectaron APs en modo activo");
    return false;
  }

  float totalDiff = 0;
  for (auto &ap : calibrationData) {
    // Buscar mismo AP en scan actual
    int idx = -1;
    for (int i = 0; i < n; i++) {
      if (WiFi.BSSIDstr(i) == ap.bssid) {
        idx = i;
        break;
      }
    }
    if (idx >= 0) {
      int rssi_now = WiFi.RSSI(idx);
      float diff_norm = fabs(rssi_now - ap.mean) / ap.stddev;
      totalDiff += diff_norm;
    } else {
      // AP no encontrado, contar como diferencia grande
      totalDiff += 3.0; // valor arbitrario, ajustar según prueba
    }
  }
  WiFi.scanDelete();

  // Debug
  Serial.printf("Diferencia total: %.2f\n", totalDiff);

  return (totalDiff > THRESHOLD);
}
